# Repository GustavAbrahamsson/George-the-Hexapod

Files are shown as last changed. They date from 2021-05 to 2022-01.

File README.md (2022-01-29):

# George the Hexapod

A hexapod designed, built and programmed completely from scratch.

- His name is George.
- 18 servoes
- Arduino Nano
- Li-Ion batteries
- Wirelessly controllable by *Transmitter-1*

Future improvements:
- Enhanced and smoother gait algorithm
- Better controller (Transmitter-1)
- Adapted for higher currents (too much smoke has come from George)
- Bigger and more flexible feet to dampen shocks when walking fast

WIP:
- Something to cover up all the electronics

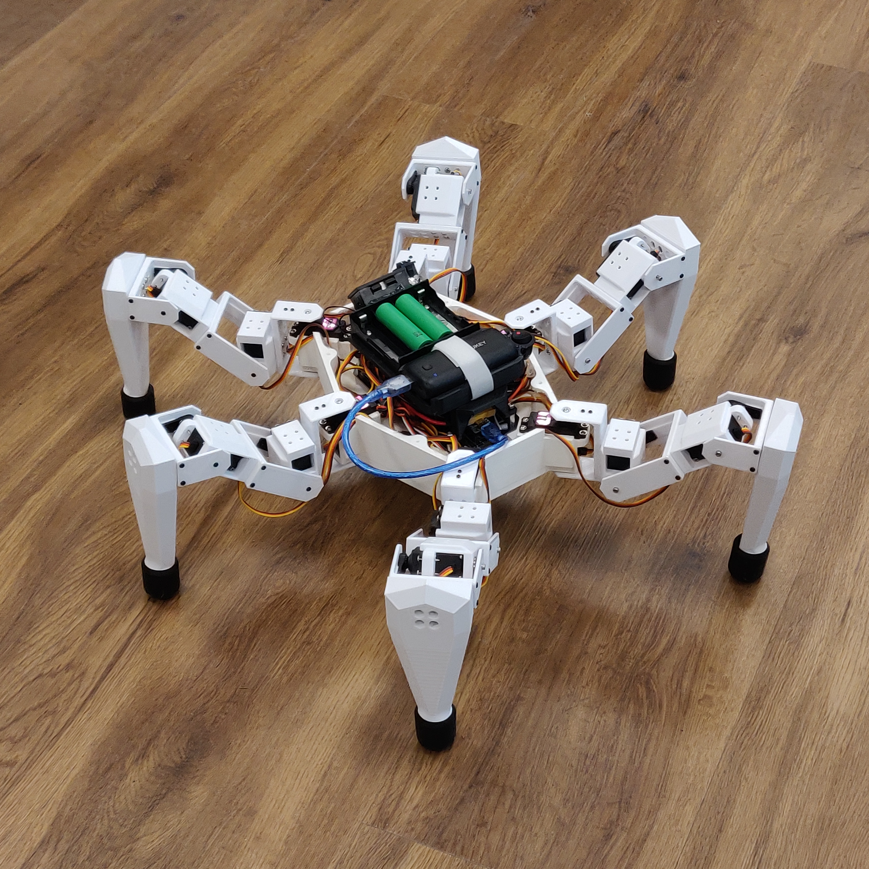
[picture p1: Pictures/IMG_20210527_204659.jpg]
 
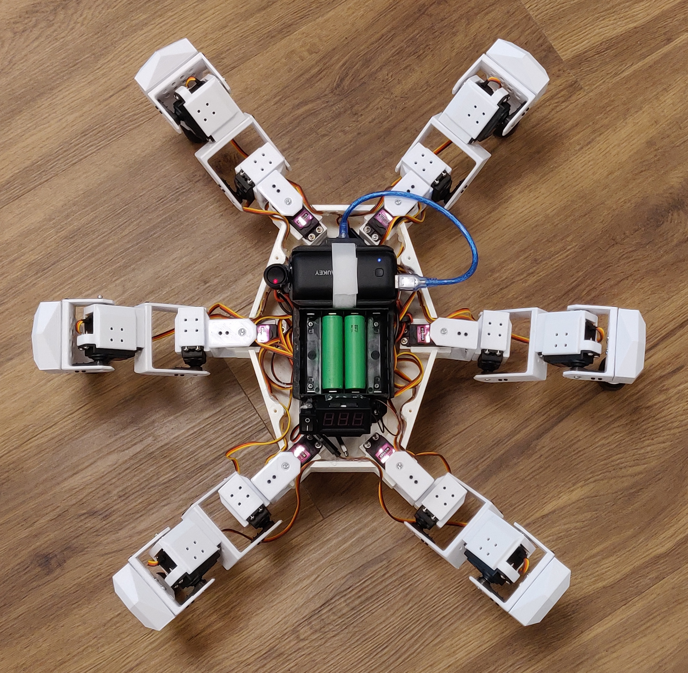
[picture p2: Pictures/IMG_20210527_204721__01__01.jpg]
 
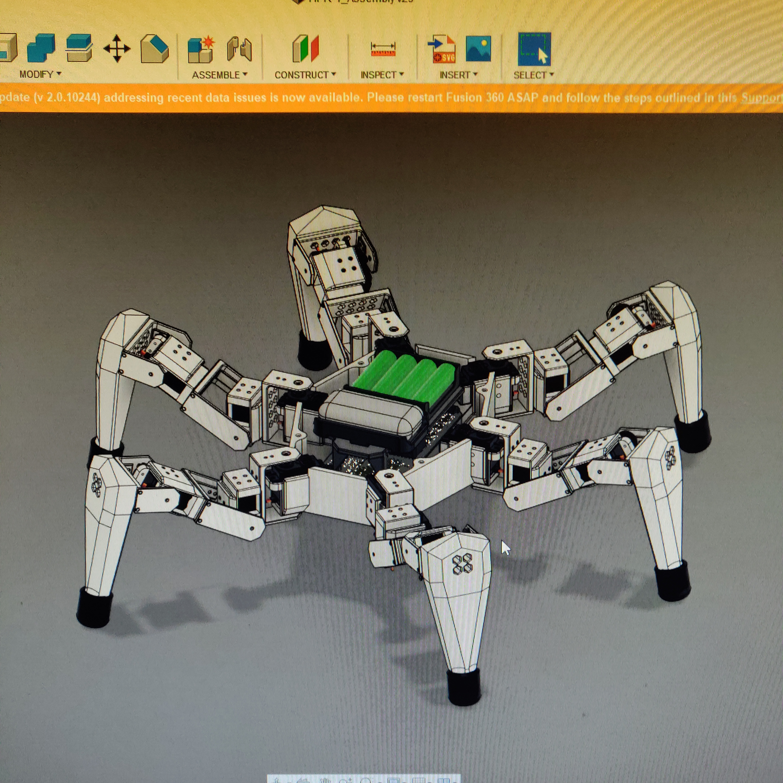
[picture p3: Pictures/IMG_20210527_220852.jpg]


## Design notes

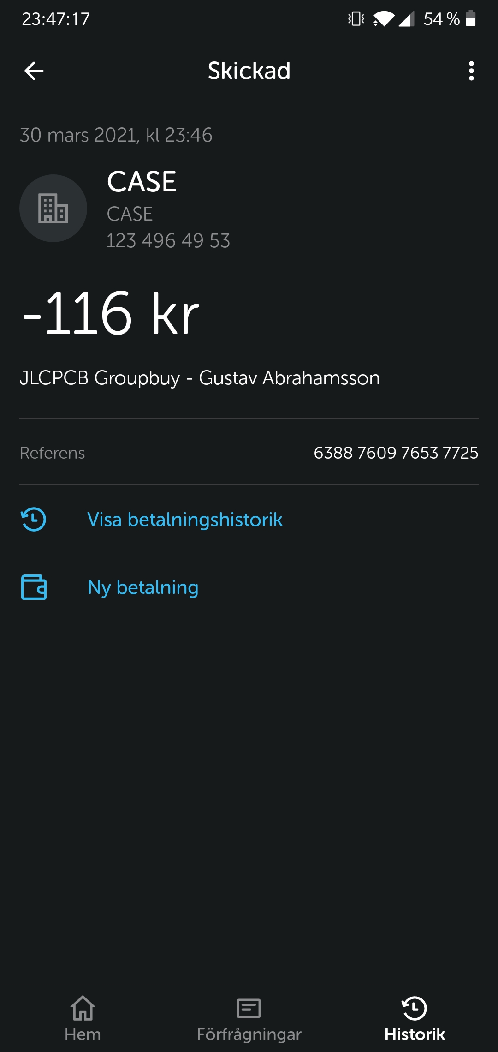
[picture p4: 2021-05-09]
Screenshot_20210330-234718.jpg

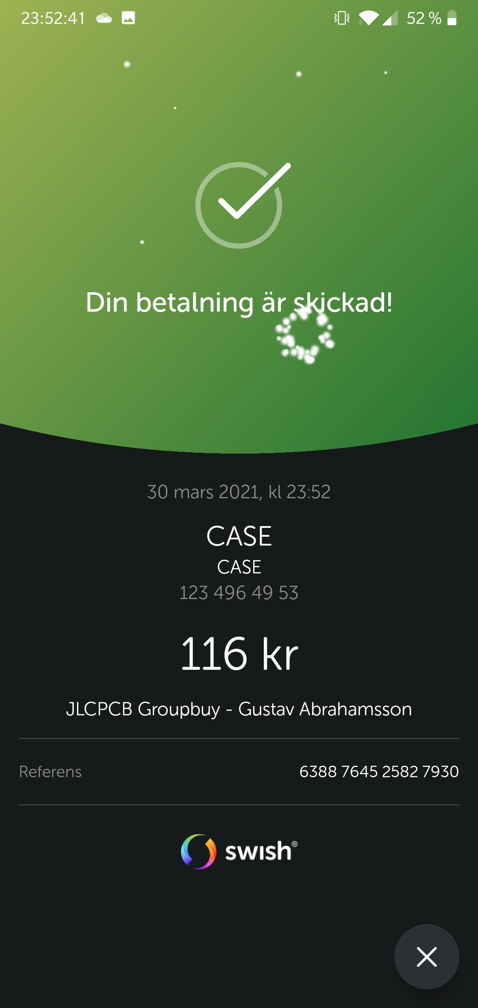
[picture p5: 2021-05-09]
Screenshot_20210330-235242.jpg

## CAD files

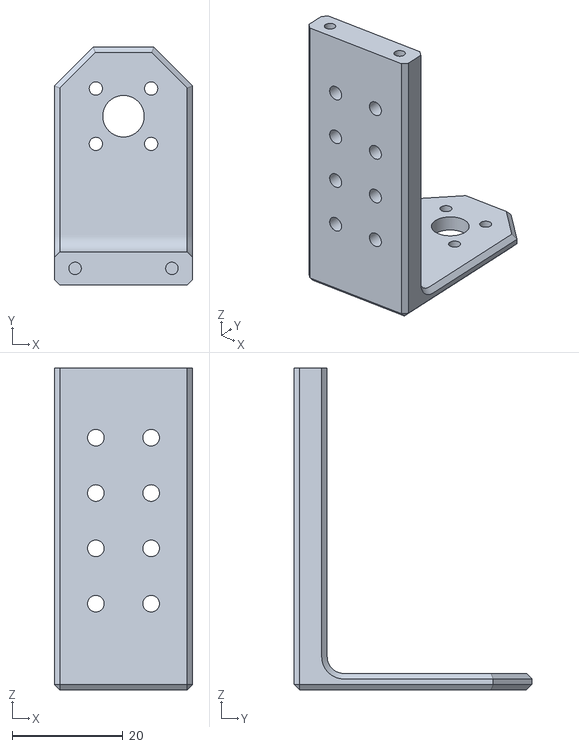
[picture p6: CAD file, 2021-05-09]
CAD/Prototype leg 1/Main_CoxaTibia.stl
25.0 x 43.0 x 58.2

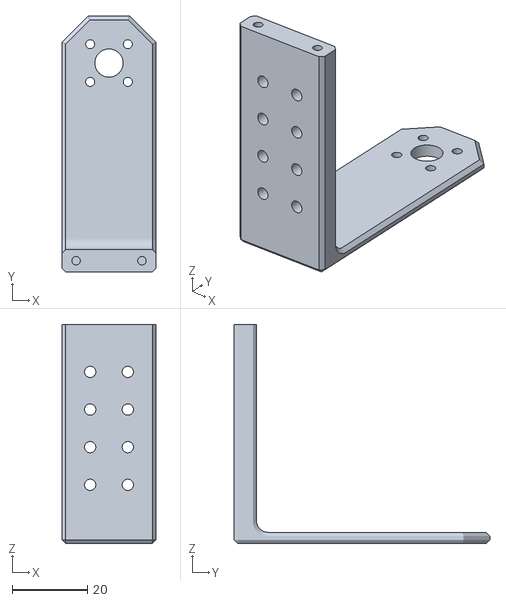
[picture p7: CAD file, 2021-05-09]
CAD/Prototype leg 1/Femur_Bracket_Main.stl
25.0 x 68.0 x 58.2

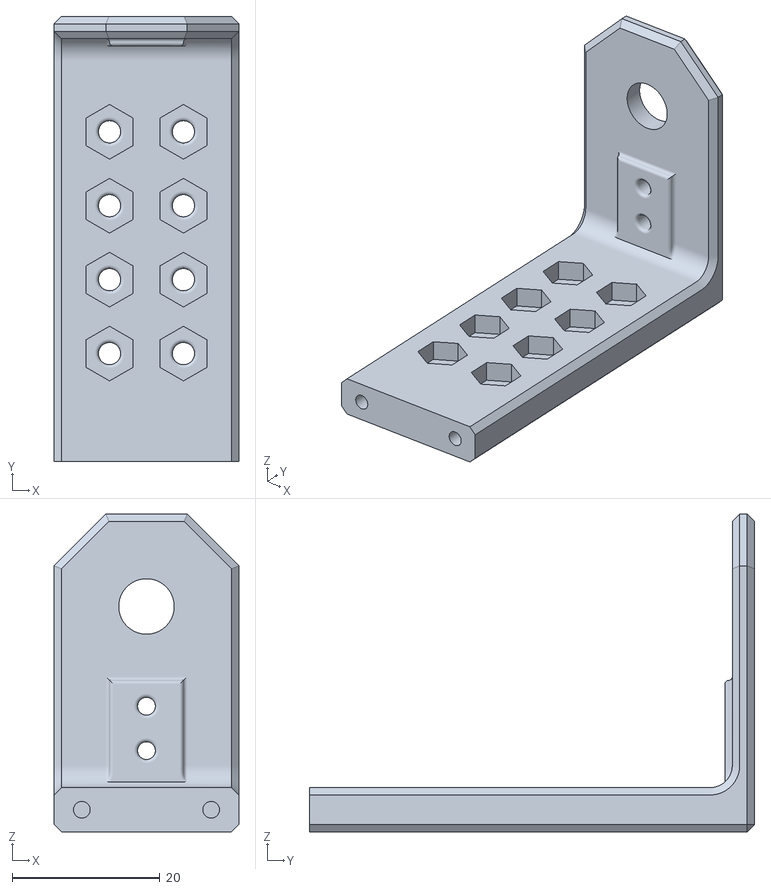
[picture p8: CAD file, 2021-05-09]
CAD/Prototype leg 2/Bracket_Main.stl
25.0 x 60.2 x 43.0

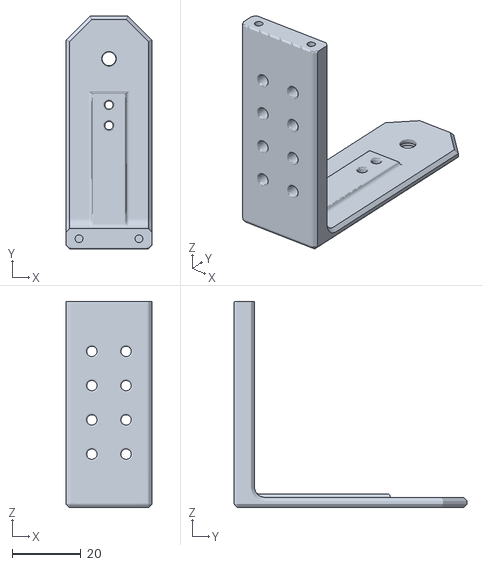
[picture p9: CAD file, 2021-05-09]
CAD/Prototype leg 3/3.5 mm hex/FemurMain.stl
25.0 x 68.0 x 60.2

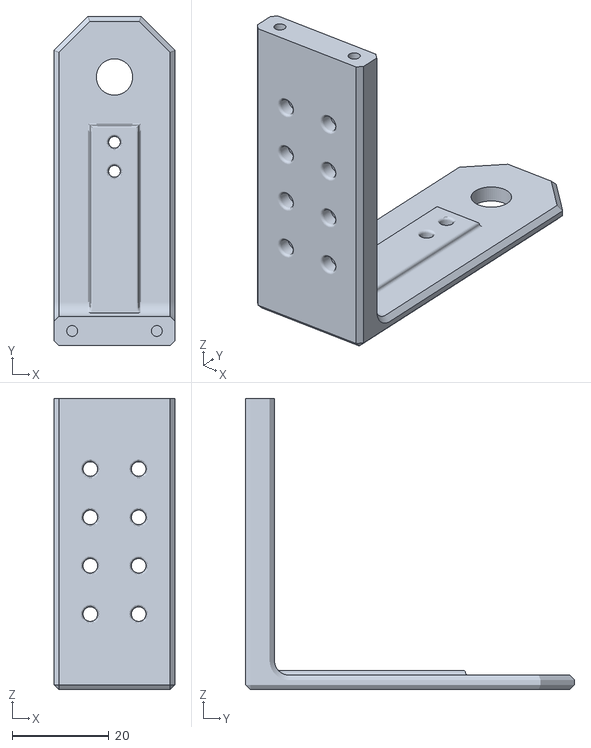
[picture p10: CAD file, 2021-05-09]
CAD/Prototype leg 2/Femur_Main.stl
25.0 x 68.0 x 60.2

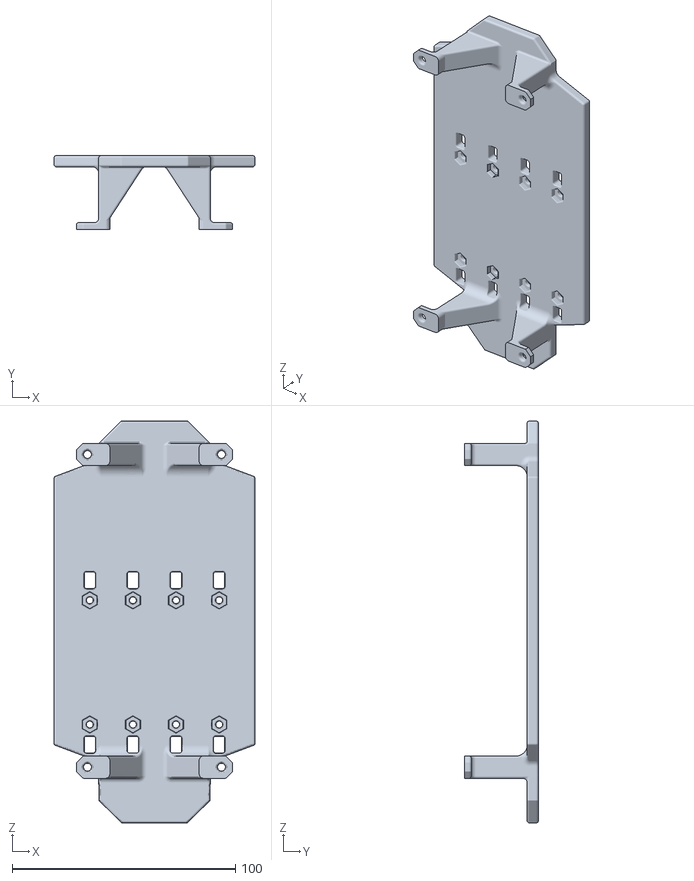
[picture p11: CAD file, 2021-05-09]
CAD/BAT holder v12.stl
90.0 x 33.0 x 180.0

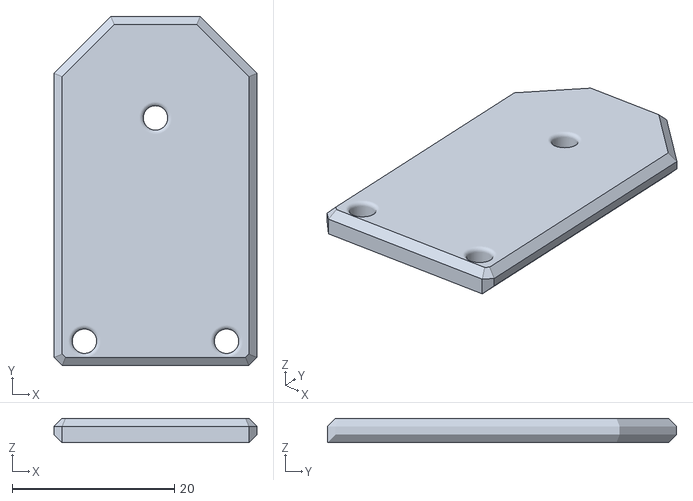
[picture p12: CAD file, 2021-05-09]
CAD/Prototype leg 2/Bracket_Sec.stl
25.0 x 43.0 x 3.00

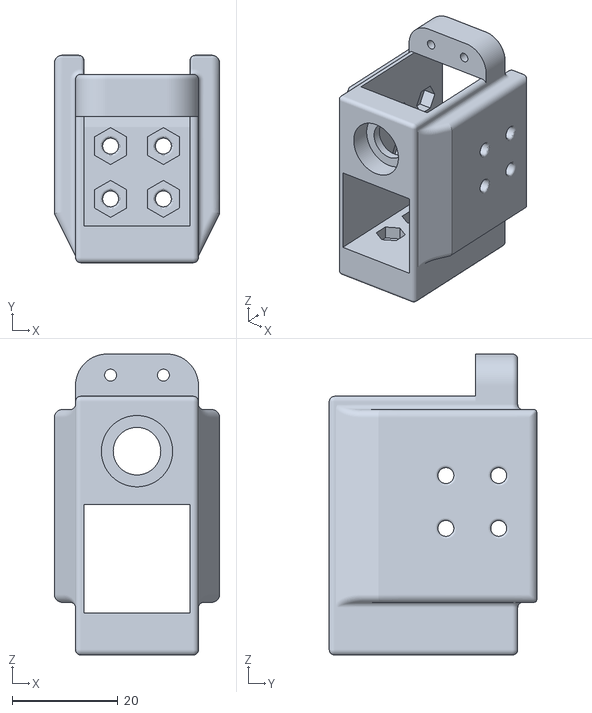
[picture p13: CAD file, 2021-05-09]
CAD/Prototype leg 3/3.5 mm hex/MG996R servo holder v13.stl
31.3 x 39.3 x 57.0

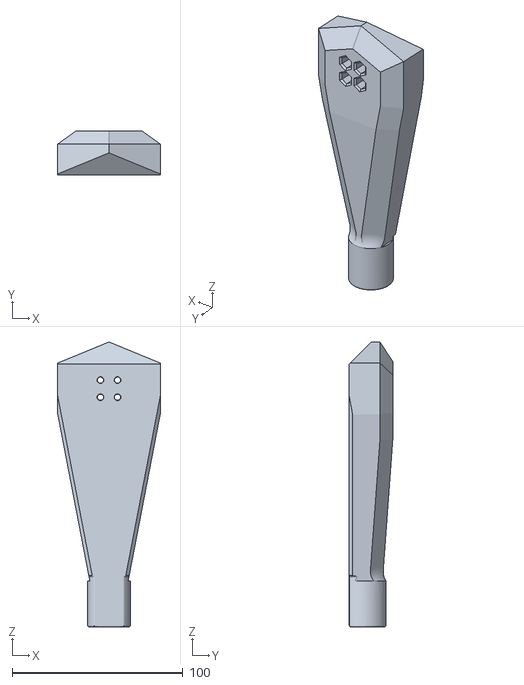
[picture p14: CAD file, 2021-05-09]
CAD/Prototype leg 3/Tibia v28.stl
60.0 x 25.5 x 166.8

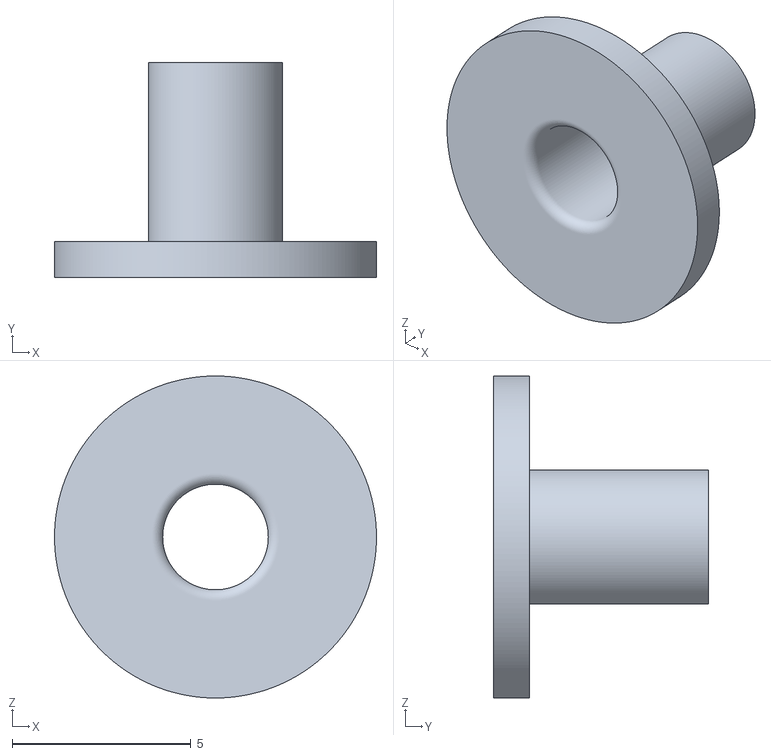
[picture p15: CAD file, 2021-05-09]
CAD/Prototype leg 3/Bearing center NEW 0.4 v3.stl
9.00 x 6.00 x 9.00

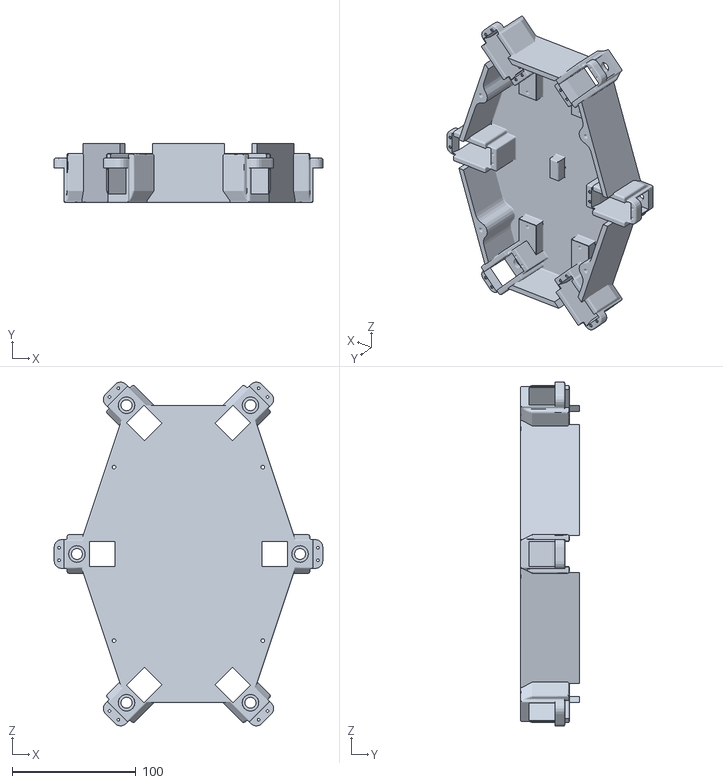
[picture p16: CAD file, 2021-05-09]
CAD/Bottom plate/Bottom- and top plate v22.stl
216.8 x 47.5 x 277.5

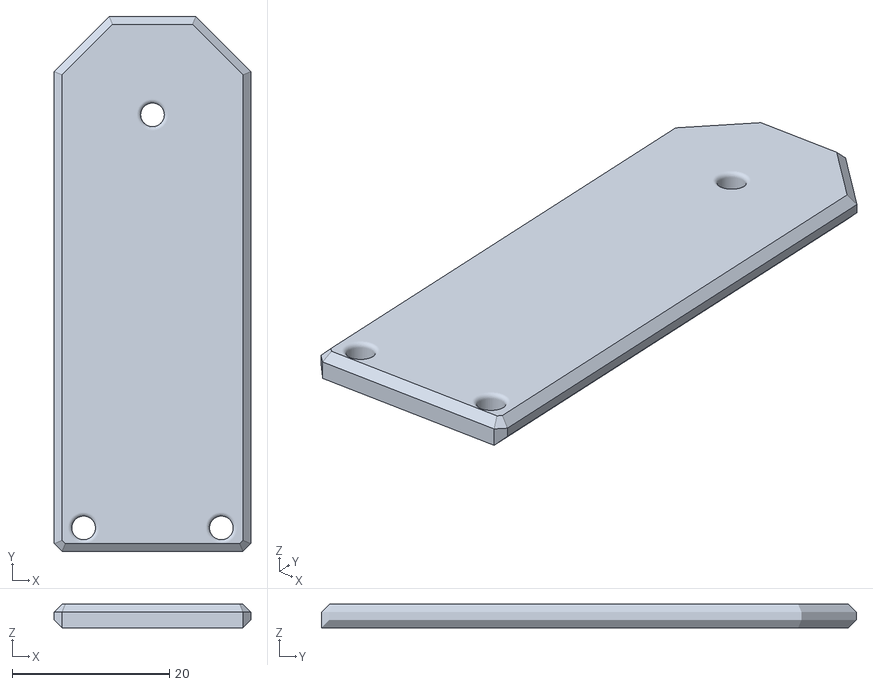
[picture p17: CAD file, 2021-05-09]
CAD/Prototype leg 2/Femur_Sec.stl
25.0 x 68.0 x 3.00

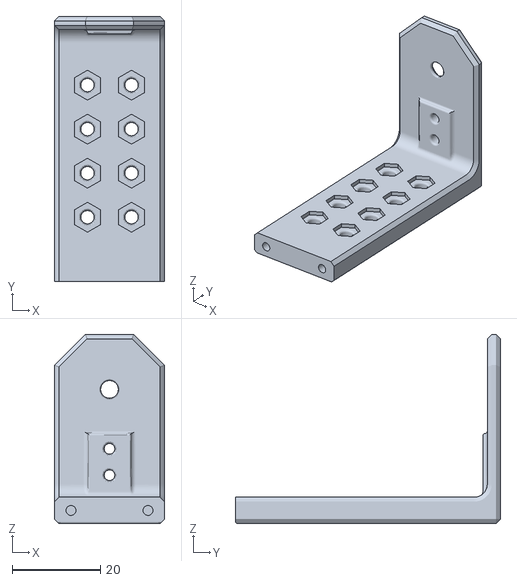
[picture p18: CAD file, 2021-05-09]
CAD/Prototype leg 3/3.5 mm hex/Bracket 3.5mm hex.stl
25.0 x 60.2 x 43.0

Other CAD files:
CAD/Prototype leg 3/CoxaMain.stl
CAD/Prototype leg 3/FemurMain.stl
CAD/Prototype leg 2/MG996R servo holder v11.stl
CAD/Prototype leg 3/3.5 mm hex/Tibia v29.stl
CAD/Prototype leg 1/Sec_CoxaTibia.stl
CAD/Bottom plate/Bottom plate test v1.step
CAD/Bottom plate/Bottom- and top plate v17.stl
CAD/Bottom plate/Bottom- and top plate v20.stl
CAD/Bottom plate/Bottom- and top plate v21.stl
CAD/Prototype leg 1/Bearing Center v16.stl
CAD/Prototype leg 1/Femur_Bracket_Sec.stl
CAD/Prototype leg 1/Imported Bearing Center v2.stl
CAD/Prototype leg 1/MG996R servo holder v7.stl
CAD/Prototype leg 1/Tibia v9.stl
CAD/Prototype leg 2/Bearing Center 0.35 v2.stl
CAD/Prototype leg 2/Bearing Center 0.4.stl
CAD/Prototype leg 2/Bearing Center v16.stl
CAD/Prototype leg 2/Imported Bearing Center v3.stl
CAD/Prototype leg 2/Tibia v13.stl
CAD/Prototype leg 3/Bearing Center 0.4 v2.stl
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

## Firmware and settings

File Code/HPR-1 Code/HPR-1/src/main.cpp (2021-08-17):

/*
My first ever hexapod. Markwtech's hexapod really helped, since I pretty much copied the idea with bearings
in the servo holders and most of the tripodGait().
*/


#include <Arduino.h>
#include <Wire.h>
#include <Adafruit_PWMServoDriver.h>
#include <SPI.h>
#include <nRF24L01.h>
#include <RF24.h>
 
Adafruit_PWMServoDriver pwm1 = Adafruit_PWMServoDriver(0x40);
Adafruit_PWMServoDriver pwm2 = Adafruit_PWMServoDriver(0x41);

// PCA9685
#define SCL A5
#define SDA A4

// NRF24L01
#define CE 7
#define CSN 8
#define MOSI 11
#define MISO 12
#define SCK 13


// Servos (Dxy: Leg at side D (L/R) x servo number y with y = 1 for coxa, 2 for femur and 3 for tibia)

// In counter clockwise direction from front left leg:


// Left side: SERVO_DRIVER_1

// Leg 1: Front left
#define S11 0 // Leg 1: Servo 1
#define S12 1 // Leg 1: Servo 2
#define S13 2 // Leg 1: Servo 3

// Leg 2: Middle left
#define S21 3 // Leg 2: Servo 1
#define S22 4 // Leg 2: Servo 2
#define S23 5 // Leg 2: Servo 3

// Leg 3: Back left
#define S31 6 // Leg 3: Servo 1
#define S32 7 // Leg 3: Servo 2
#define S33 8 // Leg 3: Servo 3


// Right side: SERVO_DRIVER_2

// Leg 4: Back right
#define S41 7 // Leg 4: Servo 1
#define S42 8 // Leg 4: Servo 2
#define S43 9 // Leg 4: Servo 3

// Leg 5: Middle right
#define S51 10 // Leg 5: Servo 1
#define S52 11 // Leg 5: Servo 2
#define S53 12 // Leg 5: Servo 3

// Leg 6: Front right
#define S61 13 // Leg 6: Servo 1
#define S62 14 // Leg 6: Servo 2
#define S63 15 // Leg 6: Servo 3

// Angle offsets for all servos:
int PWM1_SERVO_ANGLE_OFFSETS[9] = {0, 0, 0, 0, 0, 0, 0, 0, 0};
int PWM2_SERVO_ANGLE_OFFSETS[16] = {0, 0, 0, 0, 0, 0, 0, 0, 0, 0, 0, 0, 0, 0, 0, 0};

// General:
bool standUpSequence = 1;
bool sitDownSequence = 0;

const uint16_t DATA_TIME = 500; // ms

unsigned long currentTime = 0;
unsigned long previousDataTime = 0;
unsigned long previousTimeCyclic = 0;
unsigned long previousTimeStandSitUp = 0;
bool runProgram = 1;
unsigned long timer0 = 0;
unsigned long timer1 = 0;
unsigned long timer2 = 0;
unsigned long timer3 = 0;

//float M_PI = 3.1415;

// Hexapod dimensions:
const double COXA = 47; // mm
const double L1 = 95; // mm
const double L2 = 140; // mm

const int Z_HOME_VALUE = -75;

int zOffset = 0;
const uint8_t Z_OFFSET_MAX = 100;
const int8_t Z_OFFSET_MIN = -75;

/*
const int HOME_X[7] = {  0, 140,   0,  -140,  -140,    0,    140 };  //coxa-to-toe home positions (leg 1: index 1 ... leg 6: index 6)
const int HOME_Y[7] = {  0, 140,   198,  140,  -140,   -198,  -140 };
const int HOME_Z[7] = {  0, Z_HOME_VALUE,  Z_HOME_VALUE,  Z_HOME_VALUE,   Z_HOME_VALUE,   Z_HOME_VALUE,   Z_HOME_VALUE };
*/

const int HOME_X[7] = {  0, 110,   0,  -110,  -110,    0,    110 };  //coxa-to-toe home positions (leg 1: index 1 ... leg 6: index 6)
const int HOME_Y[7] = {  0, 110,   156,  110,  -110,   -156,  -110 };
const int HOME_Z[7] = {  0, Z_HOME_VALUE,  Z_HOME_VALUE,  Z_HOME_VALUE,   Z_HOME_VALUE,   Z_HOME_VALUE,   Z_HOME_VALUE };

const int BODY_X[7] = {  0, 120,   0,    -120,  -120,    0,  120 }; //body center-to-coxa servo distances 
const int BODY_Y[7] = {  0, 50,    90,     50,   -50,  -90, -50  };
const int BODY_Z[7] = {  0, 0,    0,       0,     0,    0,   0  };

int current_x[7] = {  0, 0, 0, 0, 0, 0, 0 };
int current_y[7] = {  0, 0, 0, 0, 0, 0, 0 };
int current_z[7] = {  0, 0, 0, 0, 0, 0, 0 };

int offset_x[7] = {  0, 0, 0, 0, 0, 0, 0 };
int offset_y[7] = {  0, 0, 0, 0, 0, 0, 0 };
int offset_z[7] = {  0, 0, 0, 0, 0, 0, 0 };

int target_x[7] = {  0, 0, 0, 0, 0, 0, 0 };
int target_y[7] = {  0, 0, 0, 0, 0, 0, 0 };
int target_z[7] = {  0, 0, 0, 0, 0, 0, 0 };

bool arc_leg[7] = {  0, 0, 0, 0, 0, 0, 0 };

int8_t velocity[7] = {  0, 0, 0, 0, 0, 0, 0 };

bool updateLeg[7] = {  0, 0, 0, 0, 0, 0, 0 };

// Inverse kinematics:
double A_1 = 0;
double A_2 = 0;
double B_1 = 0;
double B_2 = 0;

int16_t v0 = 0; // S_1 angle
int16_t v1 = 0; // S_2 angle
int16_t v2 = 0; // S_3 angle

uint8_t servoAngles[3];

uint8_t currentLeg;
// ORIGINAL: const double LEG_OFFSET_ANGLES[7] = {0, -0.785, -1.57, -2.36, -3.93, -4.71, -5.495};
const double LEG_OFFSET_ANGLES[7] = {0, -0.785, -1.57, -2.36, -3.93, -4.71, -5.495}; // Radians
//const double LEG_OFFSET_ANGLES[7] =   {0, 2.36, 1.57, 0.785, -3.93, -4.71, -5.495}; // Radians

// Input data from transmitter
uint16_t js1_x = 500;
uint16_t js1_y = 500;

bool js1_sw = 0;

uint16_t js2_x = 500;
uint16_t js2_y = 500;

bool tgl_sw = 0;

int16_t re_value = 0;
bool re_sw = 0;

int default_js1_x = 500;
int default_js1_y = 500;
int default_js2_x = 500;
int default_js2_y = 500;

int pos0 = 102; // 102    SG90: 107, 525
int pos180 = 475; // 475  (old: 512)

const int USMIN = 500; // 580
const int USMAX = 2500; // 2450

const int8_t ANGLE_OFFSET = 5; // degrees
const int8_t ANGLE_OFFSET_FEMUR = 14; // degrees

const uint8_t MIN_ANGLE = 10;
const uint8_t MAX_ANGLE = 170;

RF24 radio(7, 8); // CE, CSN

const byte address[6] = "35075";

double jsAngle1 = 0;
double jsAngle2 = 0;

float jsSpeed1 = 0;
float jsSpeed2 = 0;

// Gait
const uint8_t CYCLIC_TIME = 20; // ms
const uint8_t LEG_CYCLIC_TIME = 50; // ms

float strideX = 0;
float strideY = 0;
float strideR = 0;

int gait_speed = 0;
int numTicks;
int tick = 0;
int duration = 0;

bool sittingDown = 1;

int totalX, totalY, totalZ;

float sinRotX, sinRotY, sinRotZ;
float cosRotX, cosRotY, cosRotZ;
float rotOffsetX, rotOffsetY, rotOffsetZ;
float amplitudeX, amplitudeY, amplitudeZ;
float step_height_multiplier;

uint8_t tripod_case[7] = {0,1,2,1,2,1,2};

void abortProgram(String error){
  Serial.print("ERROR: ");
  Serial.println(error);
  Serial.println();
  Serial.println("PROGRAM ABORTED. HPR-1 FROZEN.");
  runProgram = 0;
  while(1);
}

void setupServoAngleOffsets(){

  PWM1_SERVO_ANGLE_OFFSETS[S12] = 4; 
  PWM1_SERVO_ANGLE_OFFSETS[S22] = 7; 
  PWM1_SERVO_ANGLE_OFFSETS[S32] = 7;

  PWM1_SERVO_ANGLE_OFFSETS[S13] = 2; 
  PWM1_SERVO_ANGLE_OFFSETS[S23] = 0; 
  PWM1_SERVO_ANGLE_OFFSETS[S33] = -2;

  
  PWM2_SERVO_ANGLE_OFFSETS[S42] = 10; 
  PWM2_SERVO_ANGLE_OFFSETS[S52] = -5; 
  PWM2_SERVO_ANGLE_OFFSETS[S62] = 4; 

  PWM2_SERVO_ANGLE_OFFSETS[S43] = -3; 
  PWM2_SERVO_ANGLE_OFFSETS[S53] = -2; 
  PWM2_SERVO_ANGLE_OFFSETS[S63] = -2; 
}

void setupNRF() {
  radio.begin();
  radio.openReadingPipe(0, address);
  radio.setPALevel(RF24_PA_MIN);
  radio.startListening();
}
String receiveData() {
  if (radio.available()) {
    char text[64] = "";
    radio.read(&text, sizeof(text));
    //Serial.println("Radio available!");
    //Serial.println(text);
    return text;
  }
  //Serial.println("Failed! Program aborted!");
  while(0); // Stay here
  return "0";
}

void fillVariable(uint16_t *receiver, char *donator, int index0, int index1, bool isSigned){
  uint16_t output = 0;
  if(isSigned) index0 += 1; // Skip sign bit if there is one
  uint16_t j = 1;
  for(int i = 0; i < (index1 - index0); i++){ // Start at 1000 if it's 5831 etc
    j *= 10;
  }
  for(int i = index0; i <= index1; i++){
    output += (donator[i]-'0') * j;
    j /= 10;
  }
  if(isSigned) output = -output;
  *receiver = output;
}

// Second one for signed int16_t
void fillVariable(int16_t *receiver, char *donator, int index0, int index1, bool isSigned){
  int16_t output = 0;
  if(isSigned) index0 += 1; // Skip sign bit if there is one
  uint16_t j = 1;
  for(int i = 0; i < (index1 - index0); i++){ // Start at 1000 if it's 5831 etc
    j *= 10;
  }
  for(int i = index0; i <= index1; i++){
    output += (donator[i]-'0') * j;
    j /= 10;
  }
  //Serial.println(donator[index0 - 1]);
  if(isSigned && (donator[index0 - 1] == '1')) output = -output;
  *receiver = output;
}

void decodeMessage(String data){
  char dataArray[24];
  strcpy(dataArray, data.c_str());

  fillVariable(&js1_x,    dataArray,  0,  3,  0);
  fillVariable(&js1_y,    dataArray,  4,  7,  0);

  if      (dataArray[8] == '1')   js1_sw = 1;
  else if (dataArray[8] == '0')   js1_sw = 0;

  fillVariable(&js2_x,    dataArray,  9,  12, 0);
  fillVariable(&js2_y,    dataArray,  13, 16, 0);

  if      (dataArray[17] == '1')   tgl_sw = 1;
  else if (dataArray[17] == '0')   tgl_sw = 0;

  fillVariable(&re_value, dataArray,  18, 22, 1);
  if (re_value < Z_OFFSET_MIN) re_value = Z_OFFSET_MIN;
  if (re_value > Z_OFFSET_MAX) re_value = Z_OFFSET_MAX;
  

  if      (dataArray[23] == '1')   re_sw = 1;
  else if (dataArray[23] == '0')   re_sw = 0;

  
  if(js1_x > 1023) js1_x = 511;
  if(js1_y > 1023) js1_y = 511;
  if(js2_x > 1023) js2_x = 511;
  if(js2_y > 1023) js2_y = 511;
  
  if(js1_x < 0) js1_x = 511;
  if(js1_y < 0) js1_y = 511;
  if(js2_x < 0) js2_x = 511;
  if(js2_y < 0) js2_y = 511;
}
 
void constrainData(){
  js1_x = constrain(js1_x,0,1023);
  js1_y = constrain(js1_y,0,1023);
  js2_x = constrain(js2_x,0,1023);
  js2_y = constrain(js2_y,0,1023);
}

void setServo(int16_t servo, int16_t angle, uint8_t pwm) {

  if(servo == S13 || servo == S23 || servo == S33 || servo == S43 || servo == S53 || servo == S63){ // If femur servo
    if(angle >= ANGLE_OFFSET_FEMUR) angle -= ANGLE_OFFSET_FEMUR; // Adjust for femur construction
  }

  if(pwm == 2 && ((servo != S41) || (servo != S51) || (servo != S61))){
    angle = 180 - angle;
  }

  if(pwm == 1){
    angle += PWM1_SERVO_ANGLE_OFFSETS[servo];
  }
  if(pwm == 2){
    angle -= PWM2_SERVO_ANGLE_OFFSETS[servo];
  }

  if (angle > 180) angle = 180;
  if (angle < 0) angle = 0;

  //uint16_t dutyCycleUS = map(angle, 0, 180, USMIN, USMAX);
  uint16_t dutyCycle = map(angle, 0, 180, pos0, pos180);
  
  /*
  if(pwm == 1){
    pwm1.writeMicroseconds(servo, dutyCycleUS);
  }else if(pwm == 2){
    pwm2.writeMicroseconds(servo, dutyCycleUS);
  }
  */
  if(pwm == 1){
    pwm1.setPWM(servo, 0, dutyCycle);
  }else if(pwm == 2){
    pwm2.setPWM(servo, 0, dutyCycle);
  }
}

void setLeg(int leg){
  if(leg < 1 || leg > 6){
    abortProgram("INVALID LEG TO 'setLeg(int leg, int angle0, int angle1, int angle2)'");
  }
  int pwmL;
  int index = 0;
  if(leg <= 3){
    pwmL = 1;
    for (int i = 0; i < 3; i++){
      index = 3*(leg-1) + i;
      setServo(index, servoAngles[i], pwmL);
    }
  }
  else if(leg >= 4) {
    pwmL = 2;
    for (int i = 0; i < 3; i++){
      index = 7 + 3*(leg-4) + i;
      //if(i == 2) servoAngles[i] = 180 - servoAngles[i];
      setServo(index, servoAngles[i], pwmL);
    }
  }
}

void hexaAngleSetAllLegs(int angle0, int angle1, int angle2){
  servoAngles[0] = angle0;
  servoAngles[1] = angle1;
  servoAngles[2] = angle2;
  for (int i = 1; i < 7; i++){
    setLeg(i);
    /*
    Serial.println(i);
    Serial.println();
    Serial.println(servoAngles[0]);
    Serial.println(servoAngles[1]);
    Serial.println(servoAngles[2]);
    */
  }
}

void calculateDirection1(){ // Joystick 1
  jsAngle1 = atan2(js1_x-512,js1_y-512) * 180/3.14;
  jsSpeed1 = sqrtf(square(js1_x-512) + square(js1_y-512)) / 512;
  if(jsSpeed1 > 1.0f) jsSpeed1 = 1.0f;
}

void calculateDirection2(){ // Joystick 2
  jsAngle2 = atan2(js2_x-512,js2_y-512) * 180/3.14;
  jsSpeed2 = sqrtf(square(js2_y-512) + square(js2_y-512)) / 512;
  if(jsSpeed2 > 1.0f) jsSpeed2 = 1.0f;
}

void calcInverseKinematics(uint8_t leg, int x, int y, int z){ // All coordinates in mm. Returns a pointer to a vector with v0, v1 and v2
//if(leg == 1){
//  Serial.print(leg); Serial.print(" "); Serial.print(x); Serial.print(" "); Serial.print(y); Serial.print(" ");Serial.println(z);
//}
  double theta = LEG_OFFSET_ANGLES[leg];

  int x_temp = x;
  
  x = cos(theta) * x      - sin(theta) * y; // Rotation matrix
  y = sin(theta) * x_temp + cos(theta) * y;
  
  double L = sqrt(square(x) + square(y));
  double HF = sqrt((square(L - COXA)) + square(z));

  if (!(HF < (L2+L1)) && (HF > (L2-L1))){
    abortProgram("IMPOSSIBLE TO REACH COORDINATES");
  }

  A_1 = atan((L - COXA) / -z);
  
  A_2 = acos((square(L2) - square(L1) - square(HF)) / (-2 * L1 * HF));
  B_1 = acos((square(HF) - square(L1) - square(L2)) / (-2 * L1 * L2));
  
  v1 = 90 -(1.57 - A_1 - A_2) * RAD_TO_DEG;
  //B_2 = 3.14 - v1 - B_1; Needed?
  v2 = 90 - (1.57 - B_1) * RAD_TO_DEG ;
  v0 = 90 - atan2(y,x) * RAD_TO_DEG;

  if(v0 < 0 || 180 < v0) abortProgram("IK calculated invalid value for v0");
  if(v1 < 0 || 180 < v1) abortProgram("IK calculated invalid value for v1");
  if(v2 < 0 || 180 < v2) abortProgram("IK calculated invalid value for v2");

  servoAngles[0] = v0;
  servoAngles[1] = v1;
  servoAngles[2] = v2;

/*
  Serial.println(L);
  Serial.println(HF);
  Serial.println(A_1);
  Serial.println(A_2);
  Serial.println(B_1);
  Serial.println(B_2);

  Serial.println();

  Serial.println(v0);
  Serial.println(v1);
  Serial.println(v2);

  Serial.println();
  Serial.println();
  */
}

void hexaMoveLegXYZ(int leg, int x, int y, int z){
  int x_in = HOME_X[leg];
  int y_in = HOME_Y[leg];
  int z_in = HOME_Z[leg];

  int x_temp;

  switch(leg){ // Ugly af fix, something wrong with rotation matrix but this works lol
    case 1: // Fixed leg 1!
      x_temp = x;
      x=y;
      y=x_temp;
      break;

    case 2: // Fixed leg 2!
      x=-x;
      break;

    case 3: // Fixed leg 3!
      x_temp = x;
      x=-y;
      y=-x_temp;
      break;
  }

  x_in = HOME_X[leg] + x;
  y_in = HOME_Y[leg] + y;
  z_in = HOME_Z[leg] + z;

  if(z_in > 0) {
    //abortProgram("POSITIVE Z VALUE TARGETED"); Is aborting really necessary?
    z_in = 0;
  }
  
  calcInverseKinematics(leg, x_in, y_in, z_in);
  
  setLeg(leg);
  current_x[leg] = x_in;
  current_y[leg] = y_in;
  current_z[leg] = z_in;
/*
  Serial.print("v0 = "); Serial.println(v0);
  Serial.print("v1 = "); Serial.println(v1);
  Serial.print("v2 = "); Serial.println(v2);
  */
}

void hexaMoveAllLegsXYZ(int x, int y, int z){
  for(int i = 1; i < 7; i++){
    if(i == 1){
      Serial.print(i); Serial.print(" "); Serial.print(x); Serial.print(" "); Serial.print(y); Serial.print(" ");Serial.println(z);
    }
    //Serial.println();
    hexaMoveLegXYZ(i,x,y,z);
  }
}

void hexaCrouch(){
  hexaAngleSetAllLegs(90,170,0);
}

void setLegTargetXYZ(int leg, int x, int y, int z, int v, bool arc){
  target_x[leg] = x;
  target_y[leg] = y;
  target_z[leg] = z;

  velocity[leg] = v;

  arc_leg[leg] = arc;

  updateLeg[leg] = 1;
}

void updateLegs(){
  int Dx;
  int Dy;
  int Dz;

  int DP;

  int x_c;
  int y_c;
  int z_c;
  
  int x_new;
  int y_new;
  int z_new;

  for (int i = 1; i < 7; i++){
    if (updateLeg[i]){
      x_c = current_x[i];
      y_c = current_y[i];
      z_c = current_z[i];
      /*
      if (x_c == target_x[i] && y_c == target_y[i] && z_c == target_z[i]){
        return;
      }
      */
      Dx = target_x[i] - x_c;
      Dy = target_y[i] - y_c;
      Dz = target_z[i] - z_c;

      int v = velocity[i];

      DP = sqrt(square(Dx) + square(Dy) + square(Dz));

      if (v >= DP) {
        v = DP;
        updateLeg[i] = 0;
      }

      x_new = x_c + Dx * v / DP;
      y_new = y_c + Dy * v / DP;
      z_new = z_c + Dz * v / DP;

      hexaMoveLegXYZ(i, x_new, y_new, z_new);

    }
  }
}

void calculateStrides()
{
  int new_js1_x = js1_x;
  int new_js1_y = js1_y;
  int new_js2_x = js2_x;

  new_js1_x -= default_js1_x; // + 1
  new_js1_y -= default_js1_y; // + 11
  new_js2_x -= default_js2_x; // - 19

  //int new_js2_y = js2_y - 512;


  jsAngle1 = atan2(new_js1_x, new_js1_y);
  jsSpeed1 = sqrt(square(new_js1_x) + square(new_js1_y));

  if(jsSpeed1 > 512) jsSpeed1 = 512;

  strideY =  50*sin(jsAngle1) * map(jsSpeed1,0,512,-100,100) / 100;
  strideX = -50*cos(jsAngle1) * map(jsSpeed1,0,512,-100,100) / 100;

  //compute stride lengths

  //strideY =  50*map(new_js1_x,-default_js1_x,1023-default_js1_x,-100,100)/100;
  //strideX = -50*map(new_js1_y,-default_js1_y,1023-default_js1_y,-100,100)/100;
  strideR =  15*map(new_js2_x,-default_js2_x,1023-default_js2_x,-100,100)/100;

  if(abs(strideR) < 3){
    strideX = strideX * 2;
    strideY = strideY * 2;
  }

  if(abs(new_js1_x) < 30){
    strideY = 0;
  }

  if(abs(new_js1_y) < 30){
    strideX = 0;
  }
  if(abs(new_js2_x) < 30){
    strideR = 0;
  }

  Serial.println(strideX);
  Serial.println(strideY);
  Serial.println(jsAngle1);
  Serial.println(jsSpeed1);
  Serial.println();
  //delay(500);
  
  /*
  strideX = 90*(0);
  strideY = 90*(1);
  strideR = 35*(0);
  */

/*
  Serial.print("strideX: "); Serial.println(strideX);
  Serial.print("strideY: "); Serial.println(strideY);
  Serial.print("strideR: "); Serial.println(strideR);
*/
  //compute rotation trig
  sinRotZ = sin(radians(strideR));
  cosRotZ = cos(radians(strideR));

  //set duration for normal and slow speed modes
  if(gait_speed == 0) duration = 1080; // 1080
  else duration = 750; // 3240
}

void calculateAmplitudes(int leg)
{
  //compute total distance from center of body to toe
  totalX = HOME_X[leg] + BODY_X[leg];
  totalY = HOME_Y[leg] + BODY_Y[leg];

  //compute rotational offset
  rotOffsetX = totalY*sinRotZ + totalX*cosRotZ - totalX;
  rotOffsetY = totalY*cosRotZ - totalX*sinRotZ - totalY;

  //compute X and Y amplitude and constrain to prevent legs from crashing into each other
  amplitudeX = ((strideX + rotOffsetX) / 2.0);
  amplitudeY = ((strideY + rotOffsetY) / 2.0);
  amplitudeX = constrain(amplitudeX, -50, 50);
  amplitudeY = constrain(amplitudeY, -50, 50);

  //compute Z amplitude
  if(abs(strideX + rotOffsetX) > abs(strideY + rotOffsetY))
    amplitudeZ = step_height_multiplier * (strideX + rotOffsetX) / 4.0;
  else
    amplitudeZ = step_height_multiplier * (strideY + rotOffsetY) / 4.0;
}

void tripodGait(){

  if((abs(js1_x-512) > 30) || (abs(js1_y-512) > 30) || (abs(js1_x-512) > 30) ||(abs(js2_y-512) > 30)|| (tick > 0)){
    //Serial.println("tripodGait()");
    calculateStrides();
    numTicks = round(duration / CYCLIC_TIME / 2.0);
    for(int i = 1; i < 7; i++){
      calculateAmplitudes(i);
      switch (tripod_case[i]){
      case 1: // Removed HOME_`[i] everywhere here since it's already the origin!
        current_x[i] = -amplitudeX*cos(M_PI*tick/numTicks);
        current_y[i] = -amplitudeY*cos(M_PI*tick/numTicks);
        current_z[i] = abs(amplitudeZ)*sin(M_PI*tick/numTicks);
        if(tick >= numTicks-1) tripod_case[i] = 2;
        break;
      
      case 2: // Removed HOME_`[i] everywhere here since it's already the origin!
        current_x[i] = amplitudeX*cos(M_PI*tick/numTicks);
        current_y[i] = amplitudeY*cos(M_PI*tick/numTicks);
        current_z[i] = 0;
        if(tick >= numTicks-1) tripod_case[i] = 1;
        break;
      }
    }
    if(tick < numTicks-1) tick++;
    else tick = 0;
  }
}
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
void loop() {

  currentTime = millis();

  if(currentTime - previousDataTime > CYCLIC_TIME*7){

    //Serial.println("Data");
    previousDataTime = currentTime;

    dataFunction();
  }

  if(currentTime - previousTimeCyclic > CYCLIC_TIME){
    previousTimeCyclic = currentTime;

    if(js1_sw && !re_sw){
      timer1 += CYCLIC_TIME;
      if(timer1 > 1000){
        if (gait_speed == 0) gait_speed = 1;
        else gait_speed = 0;
        
        timer1 = 0;
      }
    }
    else{
      timer1 = 0;
    }
  /*
    if(re_sw){
      timer2 += CYCLIC_TIME;
      if(timer2 > 1000){
        if (sittingDown == 1) {
          standUpSequence = 1;
        }
        else{
          sitDownSequence = 1;
        }
        timer2 = 0;
      }
    }
    else timer2 = 0;
*/
    if(standUpSequence){
      Serial.println("standupSequence");
      zOffset -= 1;
      Serial.println(zOffset);
      delay(5);
      if(zOffset <= Z_HOME_VALUE){
        zOffset = 0;
        standUpSequence = 0;
        sittingDown = 0;
      }
      hexaMoveAllLegsXYZ(0,0, zOffset - Z_HOME_VALUE);
    }
    /*
    if(sitDownSequence){
          Serial.println("sitDownSequence");
          zOffset += 1;
          Serial.println(zOffset);
          delay(5);
          if(zOffset >= -Z_HOME_VALUE){
            zOffset = 0;
            sitDownSequence = 0;
            sittingDown = 1;
          }
          hexaMoveAllLegsXYZ(0,0, zOffset + Z_HOME_VALUE);
        }
    */
    else if(tgl_sw){
      //Serial.println("Main loop");

      //Serial.println(js1_sw);
      //Serial.println(re_sw);
      /*
      if(js1_sw && re_sw){
        timer0 += CYCLIC_TIME;
        if(timer0 > 1000){
          //hexaMoveAllLegsXYZ(0,0,-Z_HOME_VALUE);
          //goHome();
          runProgram = !runProgram;
          timer0 = 0;
          abortProgram("ROBOT RESET TO HOME. REBOOT TO USE");
        }
      }
      else{
        timer0 = 0;
      }
      */

      
      if(2*re_value < Z_OFFSET_MAX && 2*re_value > Z_OFFSET_MIN) zOffset = -2*re_value; // Control height offset with rotary encoder
      //else zOffset = 0;

      tripodGait();

      writeAllLegs();
      /*
      Serial.println(js1_x);
      Serial.println(js1_y);

      int x_in = map(js1_x,0,1023,-75,75);
      int y_in = map(js1_y,0,1023,-75,75);
      int z_in = -10;

      Serial.println(x_in);
      Serial.println(y_in);
  
      hexaMoveLegXYZ(1,-x_in,y_in,z_in);
      */
      /*
      if(runProgram){ // Main program
        hexaMoveAllLegsXYZ(0,0,0);
      }
      */
    }
  }

/*
  Serial.print("js1_x = ");     Serial.print(js1_x);    Serial.print(" | ");
  Serial.print("js1_y = ");     Serial.print(js1_y);    Serial.print(" | ");
  Serial.print("js1_sw = ");    Serial.print(js1_sw);   Serial.println(" | ");
  
  Serial.print("js2_x = ");     Serial.print(js2_x);    Serial.print(" | ");
  Serial.print("js2_y = ");     Serial.print(js2_y);    Serial.println(" | ");
  
  Serial.print("tgl_sw = ");    Serial.print(tgl_sw);   Serial.println(" | ");

  Serial.print("re_value = ");  Serial.print(re_value); Serial.print(" | ");
  Serial.print("re_sw = ");     Serial.print(re_sw);    Serial.println(" | ");


  Serial.print("\n\n\n");
  
*/
/*
  for(int i = -90; i < 90; i++){
    setServo(0,90 + i, 1);
    delay(50);
  }
  delay(1000);

  for(int i = 90; i > -90; i--){
    setServo(0,90 + i, 1);
    delay(50);
  }
*/

/*
  delay(3000);
  setServo(15,0,1);
  delay(3000);
  setServo(15,90,1);
  delay(3000);
  setServo(15,180,1);
  */
}

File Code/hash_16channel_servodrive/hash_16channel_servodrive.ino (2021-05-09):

#include <Servo.h>
#include <Adafruit_PWMServoDriver.h>

Adafruit_PWMServoDriver pwm = Adafruit_PWMServoDriver();

int pos0 = 102;
int pos180 = 512;

void setup() {
  Serial.begin(9600);
  Serial.println("GPIO test!");
  pwm.begin();
  pwm.setPWMFreq(50);

  delay(3000);
  initial_position();
  delay(3000);
}

void loop() {
  say_hi();
  delay(2000);
  shake_hand();
  delay(2000);
  hands_up();
  delay(2000);
  hands_down();
  delay(2000);
  double_biceps();
  delay(2000);
  ape_move();
  delay(2000);
  hip_shake();
  delay(2000);

}
void setServo(int servo, int angle) {
  int duty;
  duty = map(angle, 0, 180, pos0, pos180);
  pwm.setPWM(servo, 0, duty);
}

void initial_position() {
  setServo(8, 0);
  setServo(9, 0);
  setServo(10, 20);
  setServo(11, 90);
  setServo(12, 150);
  setServo(13, 30);
  setServo(14, 30);
  setServo(15, 90);

  setServo(0, 180);
  setServo(1, 180);
  setServo(2, 160);
  setServo(3, 90);
  setServo(4, 30);
  setServo(5, 150);
  setServo(6, 150);
  setServo(7, 90);
}
//********************say hi********************//
void say_hi() {
  for (int i = 0; i <= 180; i++) {
    setServo(8, 0 + i);
    if (i <= 90) {
      setServo(9, 0 + i);
    }
    if (i <= 40) {
      setServo(10, 20 + i);
    }
    delay(15);
  }
  for (int i = 1; i <= 3; i++) {
    for (int i = 0; i <= 60; i++) {
      setServo(10, 60 + i);
      delay(15);
    }
    for (int i = 0; i <= 60; i++) {
      setServo(10, 120 - i);
      delay(15);
    }
  }
  for (int i = 0; i <= 180; i++) {
    setServo(8, 180 - i);
    if (i <= 90) {
      setServo(9, 90 - i);
    }
    if (i <= 40) {
      setServo(10, 60 - i); //10
    }
    delay(15);
  }
}
//********************shake hand********************//
void shake_hand() {
  for (int i = 0; i <= 40; i++) {
    setServo(8, 0 + i);
    delay(10);
  }
  for (int i = 0; i <= 3; i++) {
    for (int i = 0; i <= 30; i++) {
      setServo(8, 40 + i);
      delay(15);
    }
    for (int i = 0; i <= 30; i++) {
      setServo(8, 70 - i);
      delay(15);
    }
  }
  for (int i = 0; i <= 40; i++) {
    setServo(8, 40 - i);
    delay(10);
  }
}
//********************hands up********************//
void hands_up() {
  for (int i = 0; i <= 180; i++) {
    setServo(8, 0 + i);
    setServo(0, 180 - i);
    delay(15);
  }
}
//********************hands down********************//
void hands_down() {
  for (int i = 0; i <= 180; i++) {
    setServo(8, 180 - i);
    setServo(0, 0 + i);
    delay(15);
  }
}
//********************double biceps********************//
void double_biceps() {
  for (int i = 0; i <= 180; i++) {
    setServo(0, 180 - i);
    setServo(8, 0 + i);
    if (i <= 90) {
      setServo(1, 180 - i);
      setServo(9, 0 + i);
    }
    delay(15);
  }
  for (int i = 0; i <= 120; i++) {
    setServo(2, 160 - i);
    setServo(10, 20 + i);
    delay(15);
  }
  for (int i = 0; i <= 120; i++) {
    setServo(2, 40 + i);
    setServo(10, 140 - i);
    delay(15);
  }
  for (int i = 0; i <= 180; i++) {
    setServo(0, 0 + i);
    setServo(8, 180 - i);
    if (i <= 90) {
      setServo(1, 90 + i);
      setServo(9, 90 - i);
    }
    delay(15);
  }
}
//********************ape move********************//
void ape_move() {
  for (int i = 0; i <= 180; i++) {
    if (i <= 90) {
      setServo(0, 180 - i);
      setServo(8, 0 + i);
    }
    if (i <= 20) {
      setServo(1, 180 - i);
      setServo(9, 0 + i);
    }
    delay(15);
  }
  delay(100);
  for (int i = 0; i <= 100; i++) {
    if (i <= 50) {
    }
    setServo(2, 160 - i);
    delay(10);
  }
  for (int i = 1; i <= 3; i++) {
    for (int i = 0; i <= 100; i++) {
      setServo(10, 20 + i);
      setServo(2, 60 + i);
      delay(10);
    }
    for (int i = 0; i <= 100; i++) {
      setServo(10, 120 - i);
      setServo(2, 160 - i);
      delay(10);
    }
  }
  for (int i = 0; i <= 100; i++) {
    if (i <= 50) {
    }
    setServo(2, 60 + i);
    delay(10);
  }
  delay(100);
  for (int i = 0; i <= 180; i++) {
    if (i <= 90) {
      setServo(0, 90 + i);
      setServo(8, 90 - i);
    }
    if (i <= 20) {
      setServo(1, 160 + i);
      setServo(9, 20 - i);
    }
    delay(15);
  }
}
//********************hip_shake********************//
void hip_shake() {
  for (int i = 0; i <= 45; i++) {
    setServo(9, 0 + i); //45
    setServo(1, 180 - i); //135
    if (i <= 25) {
      setServo(10, 20 + i); //45
      setServo(2, 160 - i); //135
    }
    delay(15);
  }
  for (int i = 0; i <= 10; i++) {
    setServo(10, 45 - (i * 2));
    setServo(2, 135 - (i * 2));
    setServo(11, 90 + i);
    setServo(15, 90 + i);
    setServo(3, 90 + i);
    setServo(7, 90 + i);
    delay(50);
  }
  for (int j = 1; j <= 3; j++) {
    for (int i = 0; i <= 20; i++) {
      setServo(10, 25 + (i * 2));
      setServo(2, 115 + (i * 2));

      setServo(11, 100 - i);
      setServo(15, 100 - i);
      setServo(3, 100 - i);
      setServo(7, 100 - i);
      delay(50);
    }
    for (int i = 0; i <= 20; i++) {
      setServo(10, 65 - (i * 2));
      setServo(2, 155 - (i * 2));

      setServo(11, 80 + i);
      setServo(15, 80 + i);
      setServo(3, 80 + i);
      setServo(7, 80 + i);
      delay(50);
    }
  }
  for (int i = 0; i <= 10; i++) {
    setServo(10, 25 + (i * 2));
    setServo(2, 115 + (i * 2));
    setServo(11, 100 - i);
    setServo(15, 100 - i);
    setServo(3, 100 - i);
    setServo(7, 100 - i);
    delay(50);
  }
  for (int i = 0; i <= 45; i++) {
    setServo(9, 45 - i); //45
    setServo(1, 135 + i); //135
    if (i <= 25) {
      setServo(10, 45 - i); //45
      setServo(2, 135 + i); //135
    }
    delay(15);
  }
}

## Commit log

2021-04-01 Correct calibration for tibia servo on prototype leg
    [main.cpp]
2021-05-09 Moved repo to root folder
    [BAT holder v12.stl, Bearing Center 0.35 v2.stl, Bearing Center 0.4 v2.stl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]
2021-05-09 Added servo definitions
2021-05-15 Inverse kinematics
    Leg offset angle needs fixing
    [main.cpp]
2021-05-15 More inverse kinematics
    Problems with coordinate systems
    [main.cpp]
2021-05-16 calcInverseKinematics() might work for all 6 legs
    Pog
2021-05-25 +++++ (!!!) First steps
    Leg 1 and leg 3 calculate the wrong coordinates.
    90° offset somehow. Leg 2 is also going in the wrong direction sometimes.
    [main.cpp]
2021-05-27 ++++++ [ GEORGE 1.0 ] !!!
    Can translate and rotate from controllers inputs.
    Todo:
    * Mess with speed:
    * duration
    * strideX and strideY can be bigger
    when not rotating
    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
2021-05-29 Adjusted speed
    Switched from cartesian (x and y) to (theta and r) when determining speed and direction. Double the stride when not rotating.
    Just before first stresstest (from CASE-lab to Emilsborg).
2021-08-16 Added (broken) feature: standupSequence
    [main.cpp]
